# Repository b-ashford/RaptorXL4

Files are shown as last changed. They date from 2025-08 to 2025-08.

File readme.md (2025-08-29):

# RaptorXL4  

RaptorXL4 is a custom breakout board I designed to prototype the [Auto-Tuner](https://github.com/b-ashford/Auto-Tuner).  
It’s built around the **STM32L431CBT6** and includes:  

- 24 MHz HSE crystal  
- On-board ST-LINK–compatible programmer/debugger  
- User LED for quick “blinky” tests  
- VDDA supply with ferrite bead filtering for cleaner ADC performance  
- Access to most MCU pins for prototyping  
- Cool raptor silkscreen 

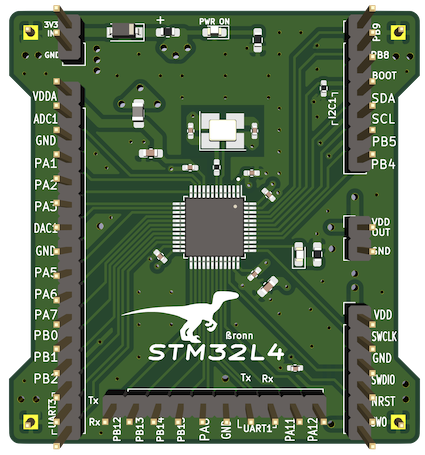
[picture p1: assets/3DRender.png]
Raptor


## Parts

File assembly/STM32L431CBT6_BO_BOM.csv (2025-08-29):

Designator | Quantity | Value | Footprint | LCSC Part #
C1, C2, C3, C4, C8 | 5 | 100n | 0402 | C307331
C5 | 1 | 10u | 0603 | C96446
C6 | 1 | 10n | 0402 | C15195
C7 | 1 | 1u | 0603 | C15849
C9, C10 | 2 | 10p | 0402 | C237160
D1 | 1 | B5619W | SOD-123 | C8598
D2 | 1 | LED_Small_Blue | 0603 | C72041
D3 | 1 | LED_Small_Red | 0603 | C2286
F1 | 1 | 500m | 0603 | C207011
FB1 | 1 | 100 @ 100MHz | 0805 | C1015
R1 | 1 | 10k | 0402 | C25744
R2 | 1 | 1.5k | 0603 | C22843
R3 | 1 | 10 | 0402 | C25077
R4 | 1 | 2.2k | 0603 | C4190
U1 | 1 | STM32L431CBT6 | LQFP-48_7.0x7.0x0.5P | C277951
X1 | 1 | 24MHz | SMD-3225_4P | C70583

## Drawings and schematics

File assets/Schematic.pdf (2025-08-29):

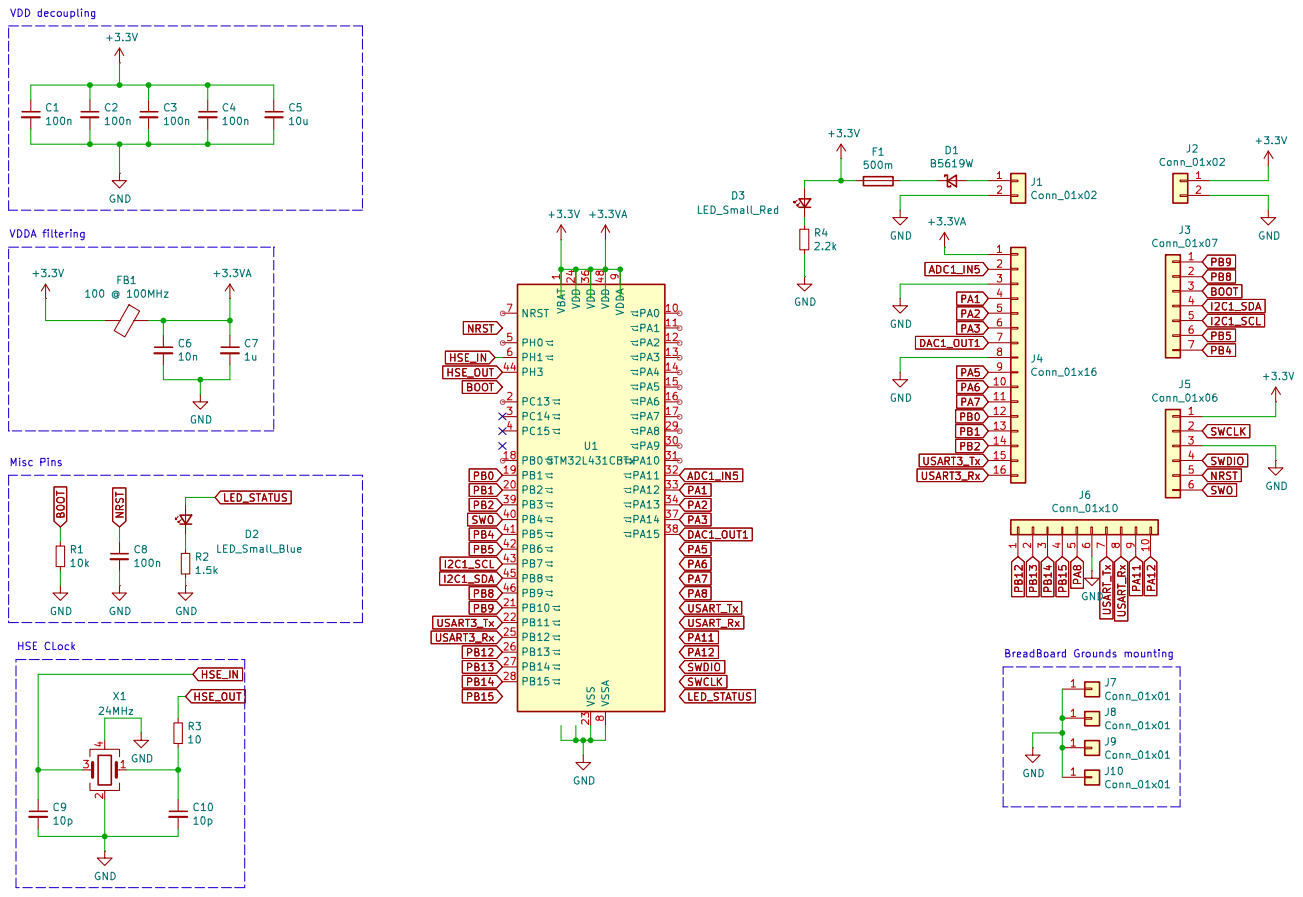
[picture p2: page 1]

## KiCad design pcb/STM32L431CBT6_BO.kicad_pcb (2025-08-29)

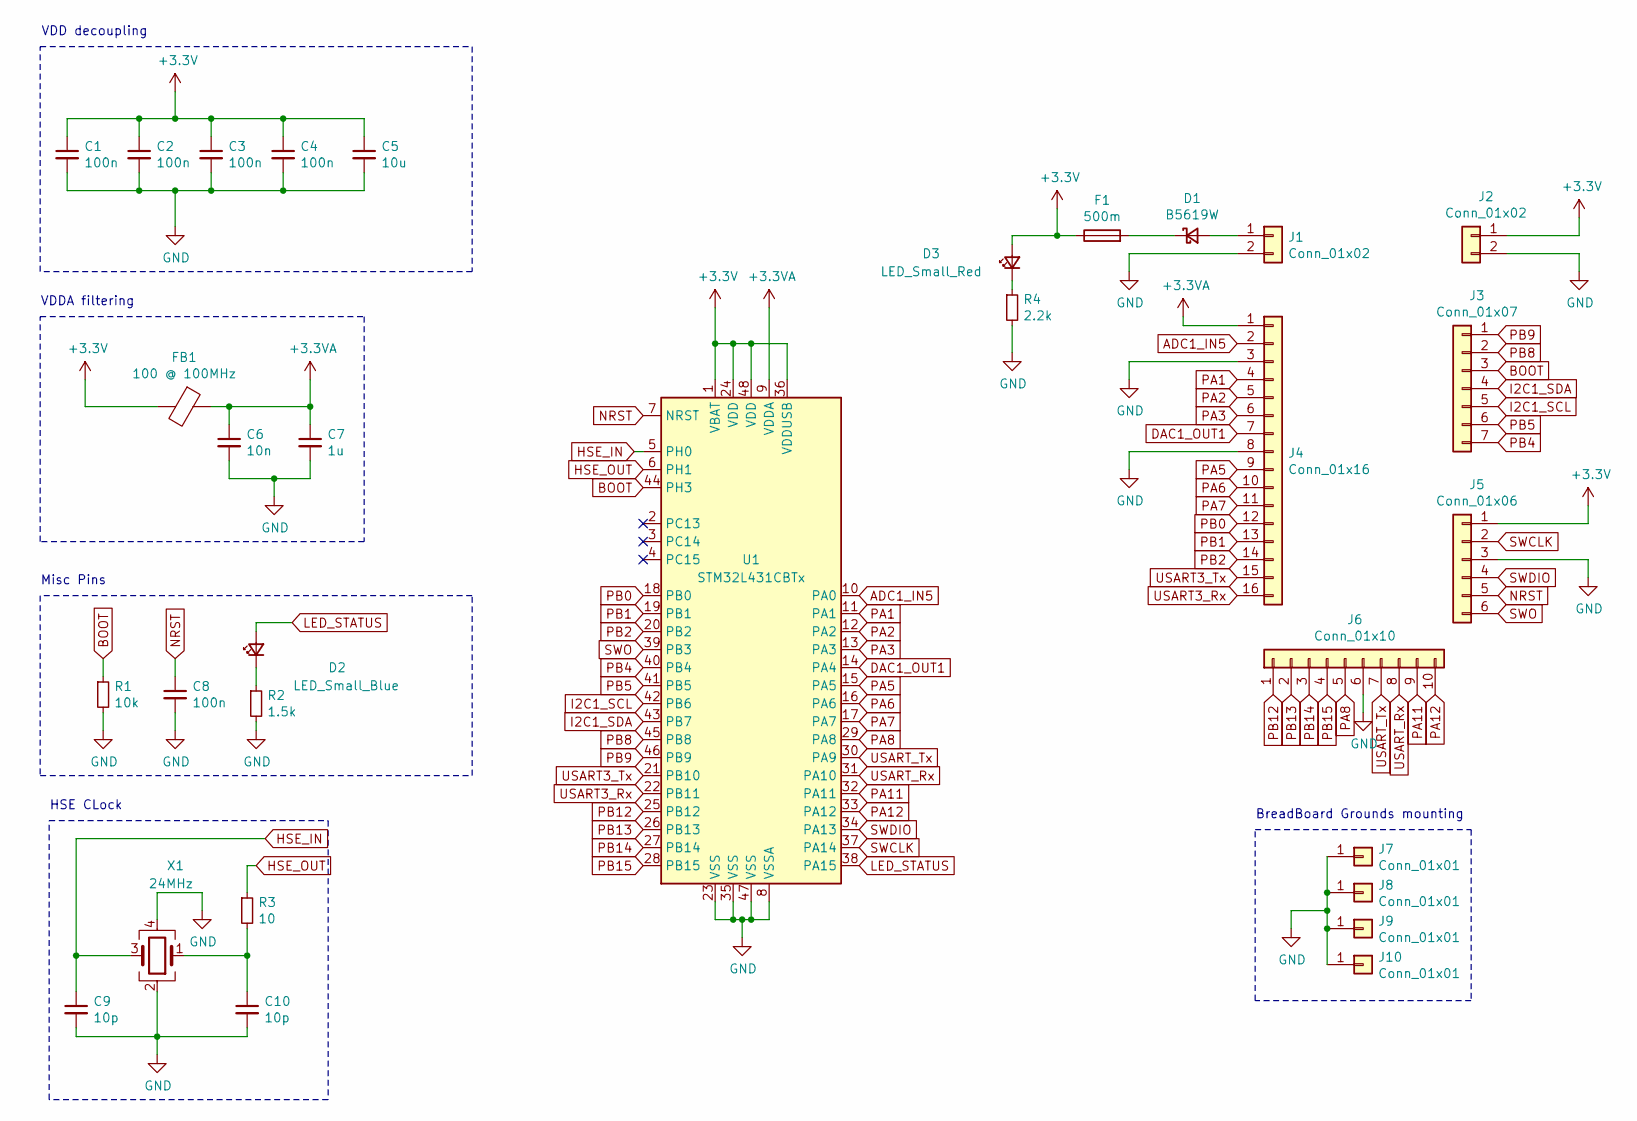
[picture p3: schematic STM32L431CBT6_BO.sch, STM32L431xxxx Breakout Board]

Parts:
C1, C2, C3, C4, C8: 100n; C_0402_1005Metric_Pad0.74x0.62mm_HandSolder
C5: 10u; C_0603_1608Metric_Pad1.08x0.95mm_HandSolder
C6: 10n; C_0402_1005Metric_Pad0.74x0.62mm_HandSolder
C7: 1u; C_0603_1608Metric_Pad1.08x0.95mm_HandSolder
C9, C10: 10p; C_0402_1005Metric_Pad0.74x0.62mm_HandSolder
D1: B5619W; D_SOD-123
D2: LED_Small_Blue; LED_0603_1608Metric_Pad1.05x0.95mm_HandSolder
D3: LED_Small_Red; LED_0603_1608Metric_Pad1.05x0.95mm_HandSolder
F1: 500m; Fuse_0603_1608Metric_Pad1.05x0.95mm_HandSolder
FB1: 100 @ 100MHz; L_0805_2012Metric_Pad1.05x1.20mm_HandSolder
J1, J2: Conn_01x02; PinHeader_1x02_P2.54mm_Vertical
J3: Conn_01x07; PinHeader_1x07_P2.54mm_Vertical
J4: Conn_01x16; PinHeader_1x16_P2.54mm_Vertical
J5: Conn_01x06; PinHeader_1x06_P2.54mm_Vertical
J6: Conn_01x10; PinHeader_1x10_P2.54mm_Vertical
J7, J8, J9, J10: Conn_01x01; PinHeader_1x01_P2.54mm_Vertical
R1: 10k; R_0402_1005Metric_Pad0.72x0.64mm_HandSolder
R2: 1.5k; R_0603_1608Metric_Pad0.98x0.95mm_HandSolder
R3: 10; R_0402_1005Metric_Pad0.72x0.64mm_HandSolder
R4: 2.2k; R_0603_1608Metric_Pad0.98x0.95mm_HandSolder
U1: STM32L431CBTx; LQFP-48_7x7mm_P0.5mm
X1: 24MHz; Crystal_SMD_3225-4Pin_3.2x2.5mm_HandSoldering

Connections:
+3.3VA: C6.1, C7.1, FB1.1, J4.1, U1.9 (VDDA)
+3V3: C1.1, C2.1, C3.1, C4.1, C5.1, D3.2 (A), F1.1, FB1.2, J2.1, J5.1, U1.1 (VBAT), U1.24 (VDD), U1.36 (VDDUSB), U1.48 (VDD)
ADC1_IN5: J4.2, U1.10 (PA0)
BOOT: J3.3, R1.1, U1.44 (PH3)
DAC1_OUT1: J4.7, U1.14 (PA4)
GND: C1.2, C2.2, C3.2, C4.2, C5.2, C6.2, C7.2, C8.2, C9.2, C10.2, J1.2, J2.2, J4.3, J4.8, J5.3, J6.6, J7.1, J8.1, J9.1, J10.1, R1.2, R2.2, R4.2, U1.8 (VSSA), U1.23 (VSS), U1.35 (VSS), U1.47 (VSS), X1.2, X1.4
HSE_IN: C9.1, U1.5 (PH0), X1.3
HSE_OUT: R3.1, U1.6 (PH1)
I2C1_SCL: J3.5, U1.42 (PB6)
I2C1_SDA: J3.4, U1.43 (PB7)
LED_STATUS: D2.2 (A), U1.38 (PA15)
NRST: C8.1, J5.5, U1.7 (NRST)
unnamed: C10.1, R3.2, X1.1
unnamed: D1.1 (K), F1.2
unnamed: D1.2 (A), J1.1
unnamed: D2.1 (K), R2.1
unnamed: D3.1 (K), R4.1
PA1: J4.4, U1.11 (PA1)
PA2: J4.5, U1.12 (PA2)
PA3: J4.6, U1.13 (PA3)
PA5: J4.9, U1.15 (PA5)
PA6: J4.10, U1.16 (PA6)
PA7: J4.11, U1.17 (PA7)
PA8: J6.5, U1.29 (PA8)
PA11: J6.9, U1.32 (PA11)
PA12: J6.10, U1.33 (PA12)
PB0: J4.12, U1.18 (PB0)
PB1: J4.13, U1.19 (PB1)
PB2: J4.14, U1.20 (PB2)
PB4: J3.7, U1.40 (PB4)
PB5: J3.6, U1.41 (PB5)
PB8: J3.2, U1.45 (PB8)
PB9: J3.1, U1.46 (PB9)
PB12: J6.1, U1.25 (PB12)
PB13: J6.2, U1.26 (PB13)
PB14: J6.3, U1.27 (PB14)
PB15: J6.4, U1.28 (PB15)
SWCLK: J5.2, U1.37 (PA14)
SWDIO: J5.4, U1.34 (PA13)
SWO: J5.6, U1.39 (PB3)
USART3_Rx: J4.16, U1.22 (PB11)
USART3_Tx: J4.15, U1.21 (PB10)
USART_Rx: J6.8, U1.31 (PA10)
USART_Tx: J6.7, U1.30 (PA9)

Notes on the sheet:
HSE CLock
VDD decoupling
VDDA filtering
Misc Pins
BreadBoard Grounds mounting

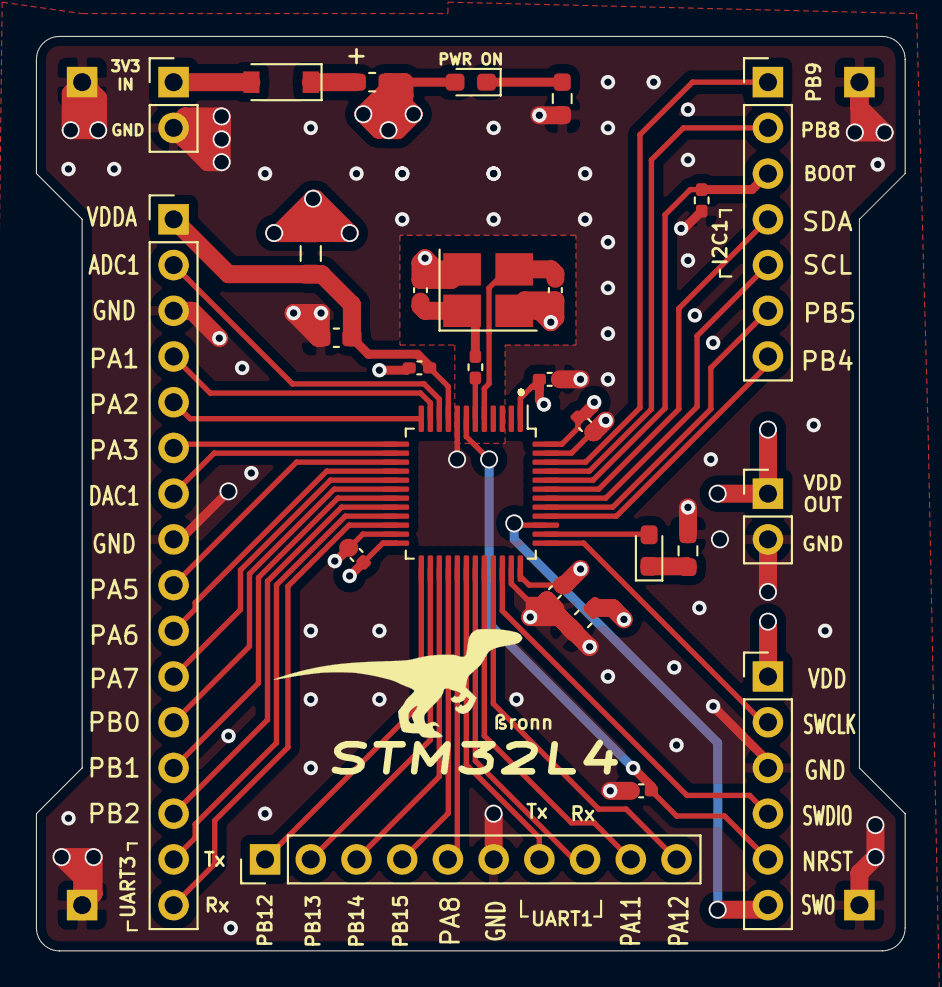
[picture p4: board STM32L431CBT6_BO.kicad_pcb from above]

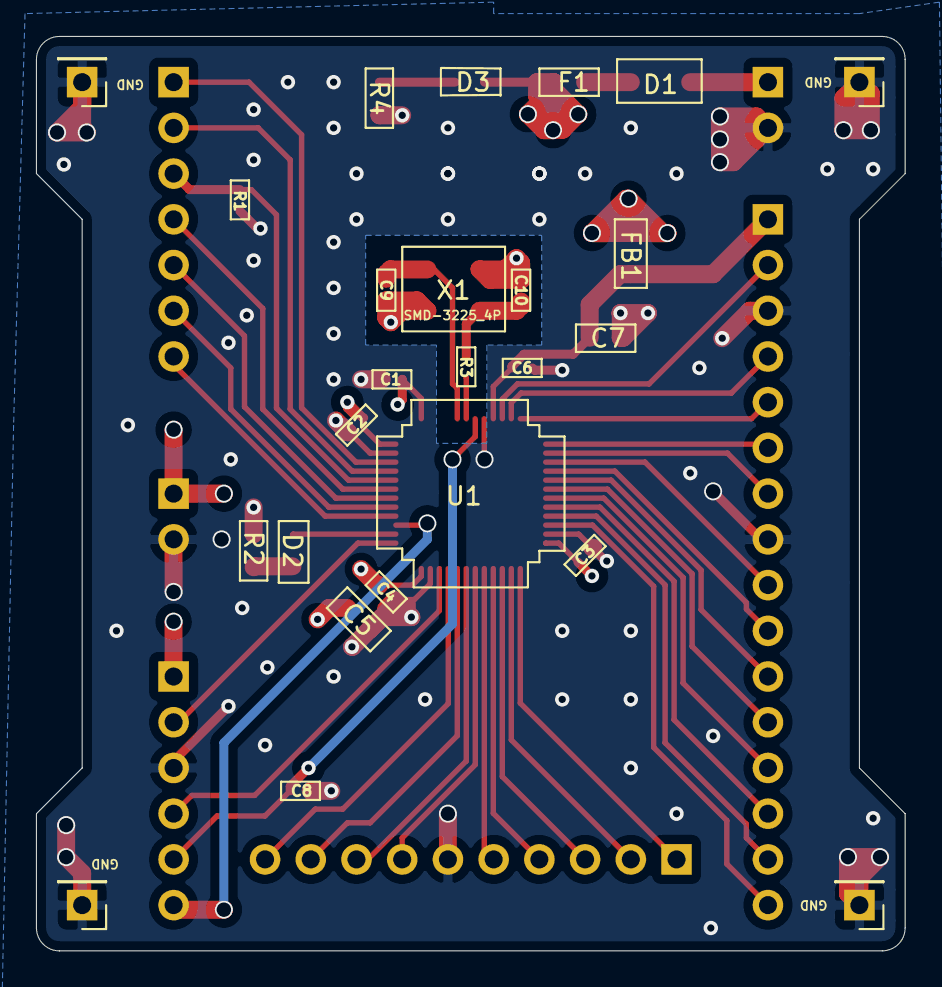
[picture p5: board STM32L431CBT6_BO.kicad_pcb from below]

Board: 4 copper layers, 48.3 x 50.8 mm, 31 parts (4 on the bottom side), 44 nets.
